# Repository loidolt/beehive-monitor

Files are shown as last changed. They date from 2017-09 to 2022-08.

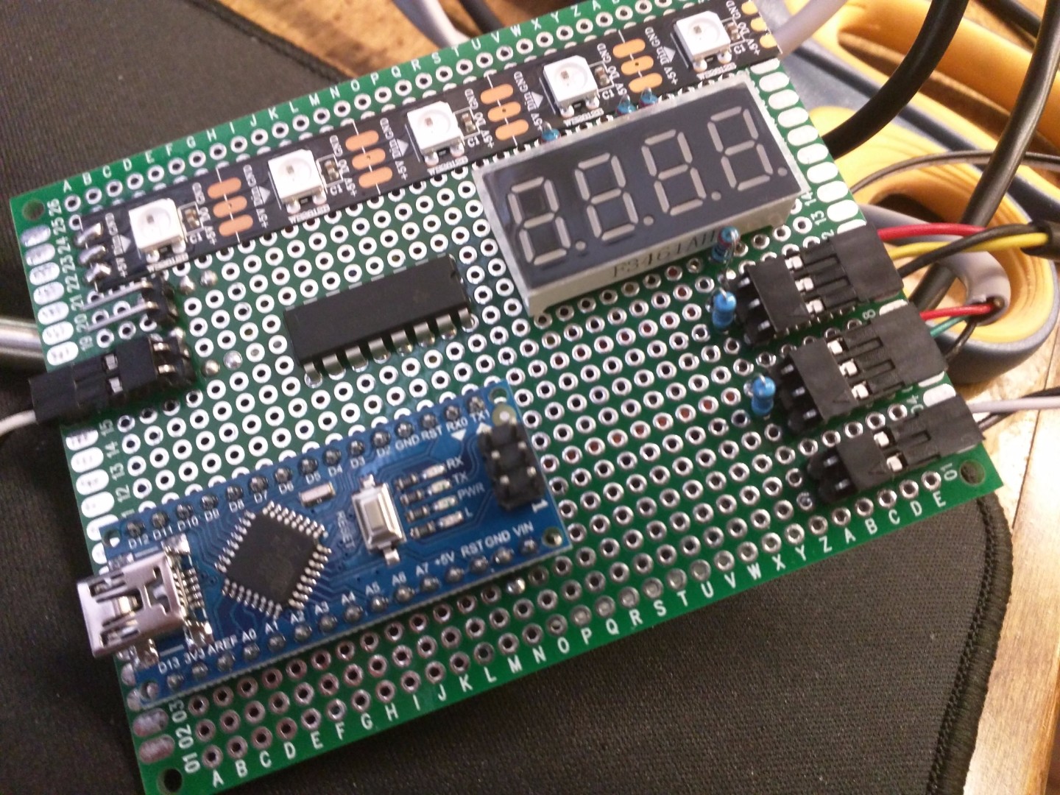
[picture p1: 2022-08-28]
images/BeeMonitorResized_Cover.jpg

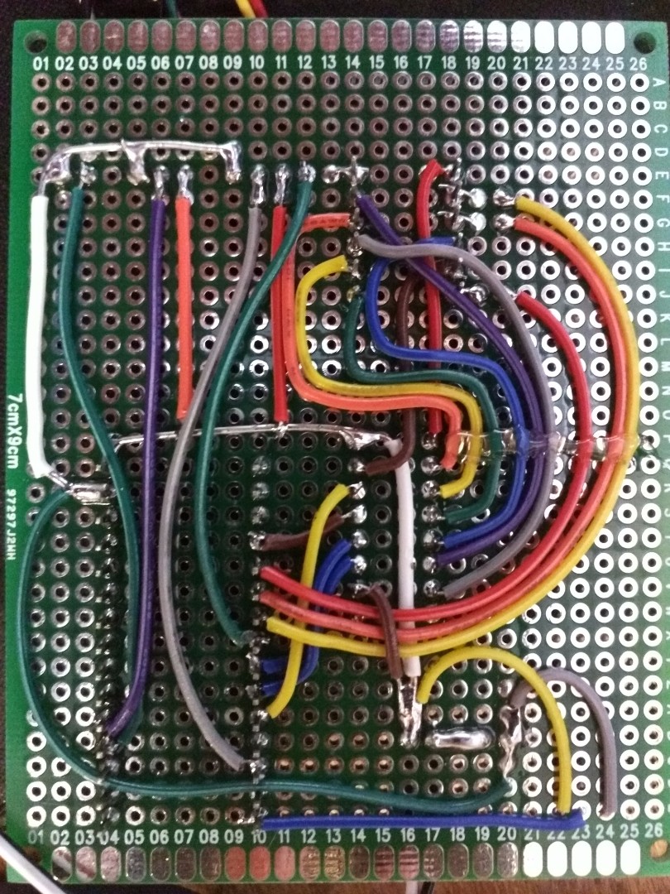
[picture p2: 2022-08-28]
images/BeeMonitorResized (1).jpg

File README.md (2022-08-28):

---
published: true
status: complete
date: 12/20/2016
tags: Electronics Outdoors
description: Beehive monitor that allows you to see the temperature and humidity of the hive.
slug: beehive-monitor
---

# Beehive Monitor

Beehive monitor that allows you to see the temperature and humidity of the hive.

## Table of Contents

- [Beehive Monitor](#beehive-monitor)
  - [Table of Contents](#table-of-contents)
  - [General Info](#general-info)
  - [Technologies](#technologies)

## General Info

This is is a beehive monitor that allows you to see the temperature and humidity of the hive. It also shows the general health of the hive using an LED strip based on ideal temperature and humidity values.

There are two temperature probes, one at the top of the hive and one that can be placed down by the hive ball to get a more accurate reading of the bees themselves. The temperature sensor at the top of the hive is also responsible for measuring humidity.

Sensor data is gathered once a minute, additionally, a rolling thirty-minute average is generated based on this data.

## Technologies
- SketchUp
- Eagle
- KiCAD
- Arduino

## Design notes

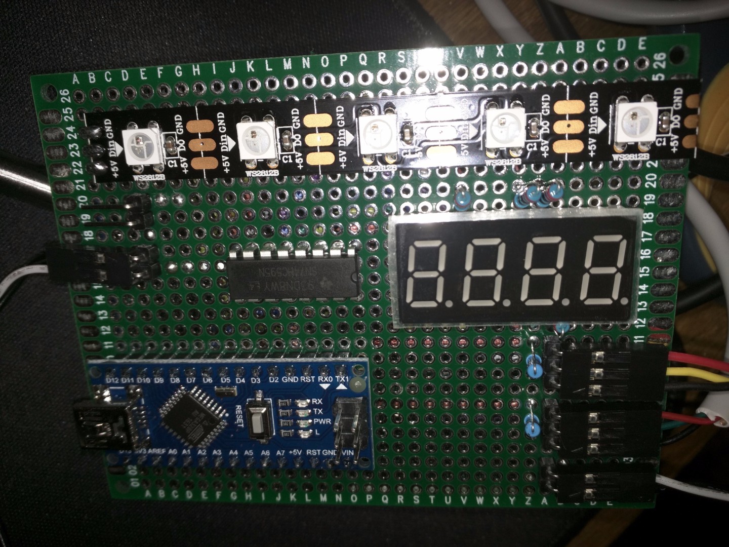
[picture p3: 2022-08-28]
images/BeeMonitorResized (7).jpg

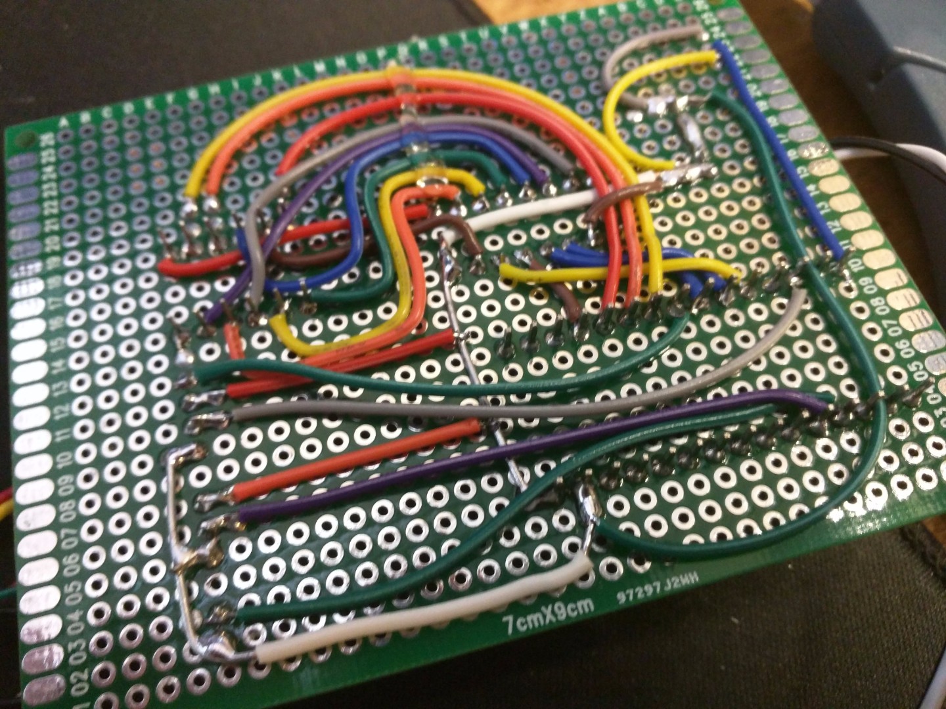
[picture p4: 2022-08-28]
images/BeeMonitorResized (3).jpg

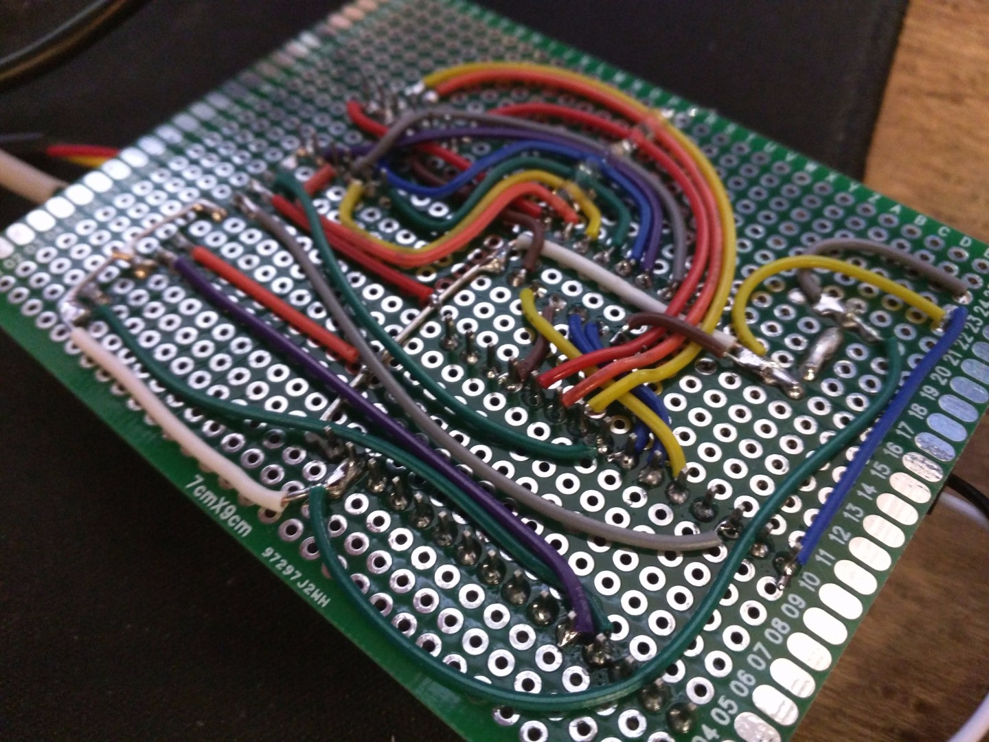
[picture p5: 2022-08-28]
images/BeeMonitorResized (4).jpg

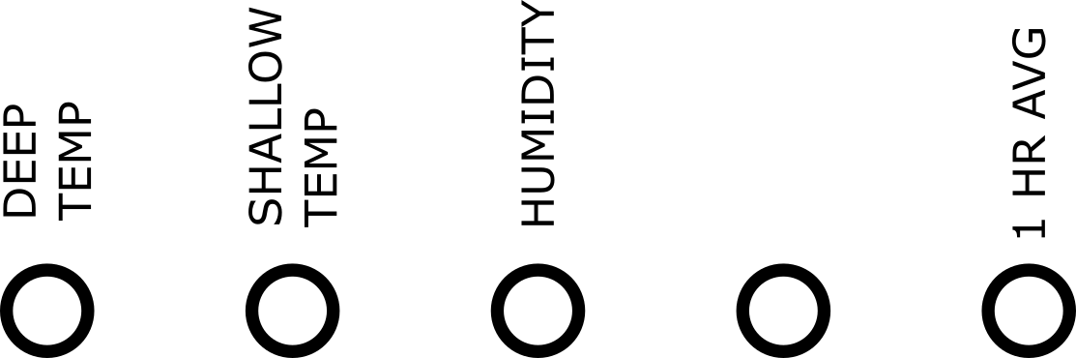
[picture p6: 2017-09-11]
firmware/SevenSegment/KeyGraphic.png

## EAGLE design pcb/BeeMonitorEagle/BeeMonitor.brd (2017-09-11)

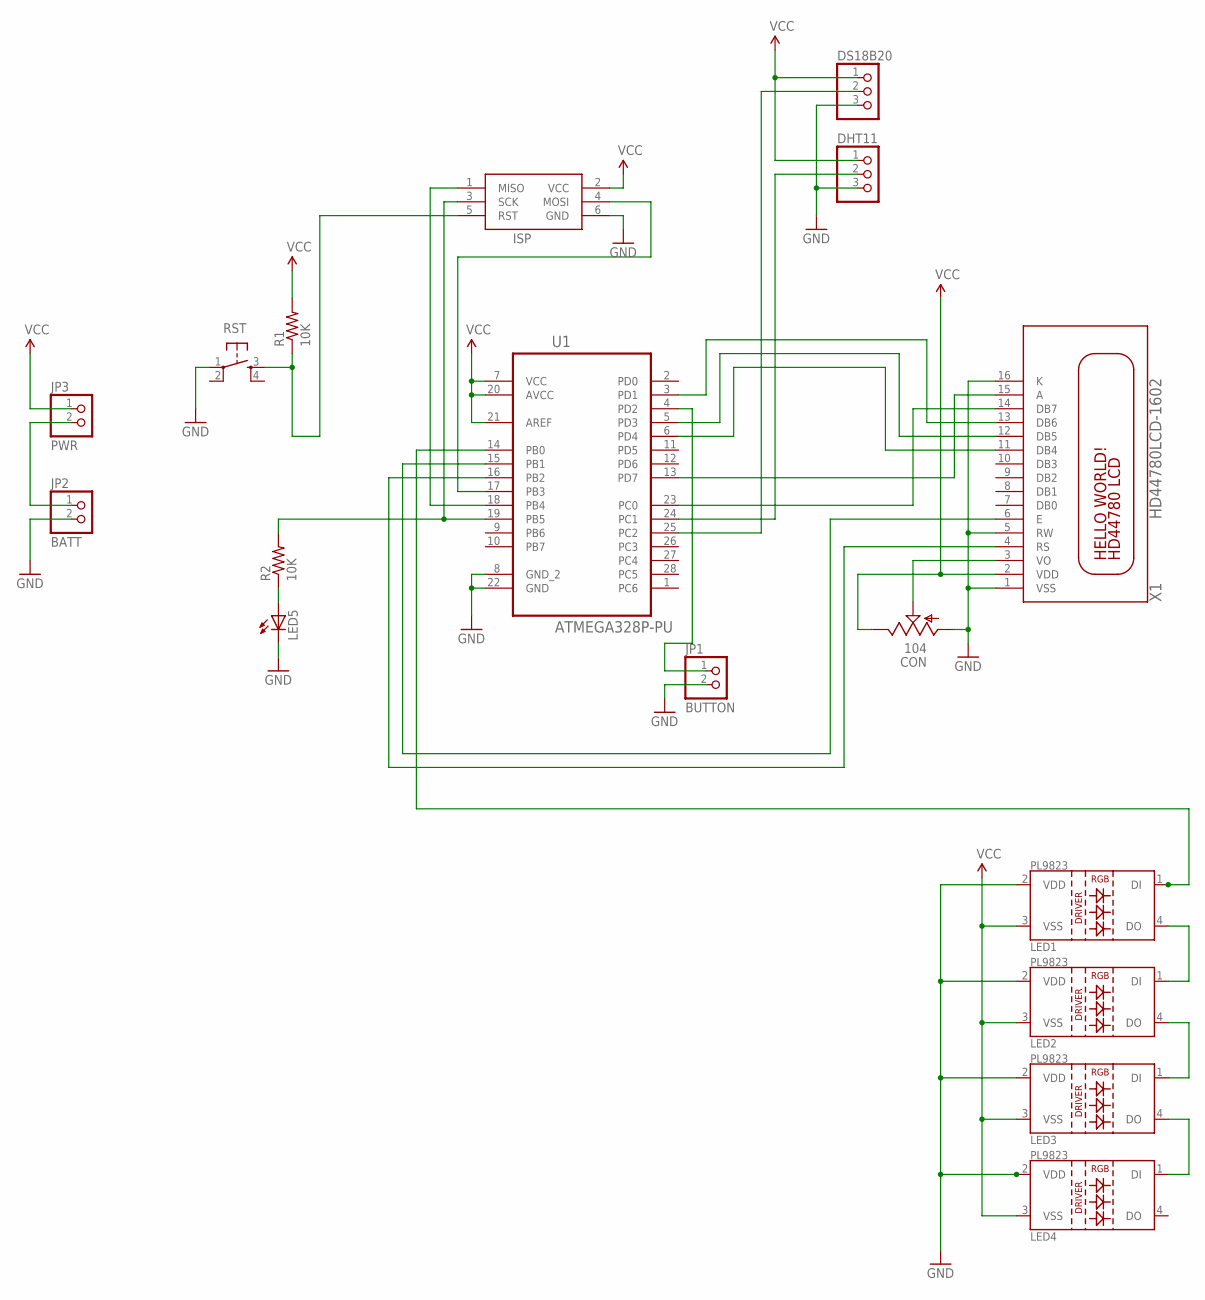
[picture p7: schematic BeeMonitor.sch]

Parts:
CON: 104; 6MM
DHT11: PINHD-1X3; 1X03
DS18B20: PINHD-1X3; 1X03
ISP: AVRISP-6; AVRISP
JP1: BUTTON; 1X02
JP2: BATT; 1X02
JP3: PWR; 1X02
LED1, LED2, LED3, LED4: LED-PL9823-F5
LED5: LED3MM
R1, R2: 10K; 0207/10
RST: TAC_SWITCHPTH; TACTILE-PTH
U1: ATMEGA328P-PU; DIP254P762X457-28
X1: HD44780LCD-1602; LCD1602

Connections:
GND: DHT11.3, DS18B20.3, ISP.6 (GND), JP1.2, JP2.2, LED1.2 (VDD), LED2.2 (VDD), LED3.2 (VDD), LED4.2 (VDD), LED5.K (C), RST.1, U1.8 (GND_2), U1.22 (GND)
unnamed: CON.S, X1.3 (VO)
unnamed: ISP.5 (RST), R1.1, RST.3
unnamed: ISP.3 (SCK), R2.2, U1.19 (PB5)
unnamed: ISP.1 (MISO), U1.18 (PB4)
unnamed: ISP.4 (MOSI), U1.17 (PB3)
unnamed: LED1.4 (DO), LED2.1 (DI)
unnamed: LED2.4 (DO), LED3.1 (DI)
unnamed: LED3.4 (DO), LED4.1 (DI)
unnamed: LED1.1 (DI), U1.14 (PB0)
unnamed: U1.3 (PD1), X1.13 (DB6)
unnamed: DHT11.2, U1.24 (PC1)
unnamed: DS18B20.2, U1.25 (PC2)
unnamed: JP1.1, U1.4 (PD2)
unnamed: U1.13 (PD7), X1.15 (A)
unnamed: U1.23 (PC0), X1.14 (DB7)
unnamed: U1.5 (PD3), X1.12 (DB5)
unnamed: U1.6 (PD4), X1.11 (DB4)
unnamed: U1.15 (PB1), X1.6 (E)
unnamed: U1.16 (PB2), X1.4 (RS)
unnamed: LED5.A, R2.1
unnamed: JP2.1, JP3.2
VCC: DHT11.1, DS18B20.1, ISP.2 (VCC), JP3.1, LED1.3 (VSS), LED2.3 (VSS), LED3.3 (VSS), LED4.3 (VSS), R1.2, U1.7 (VCC), U1.20 (AVCC), U1.21 (AREF)
VDD: CON.E, X1.2 (VDD)
VSS: CON.A, X1.1 (VSS), X1.5 (RW), X1.16 (K)

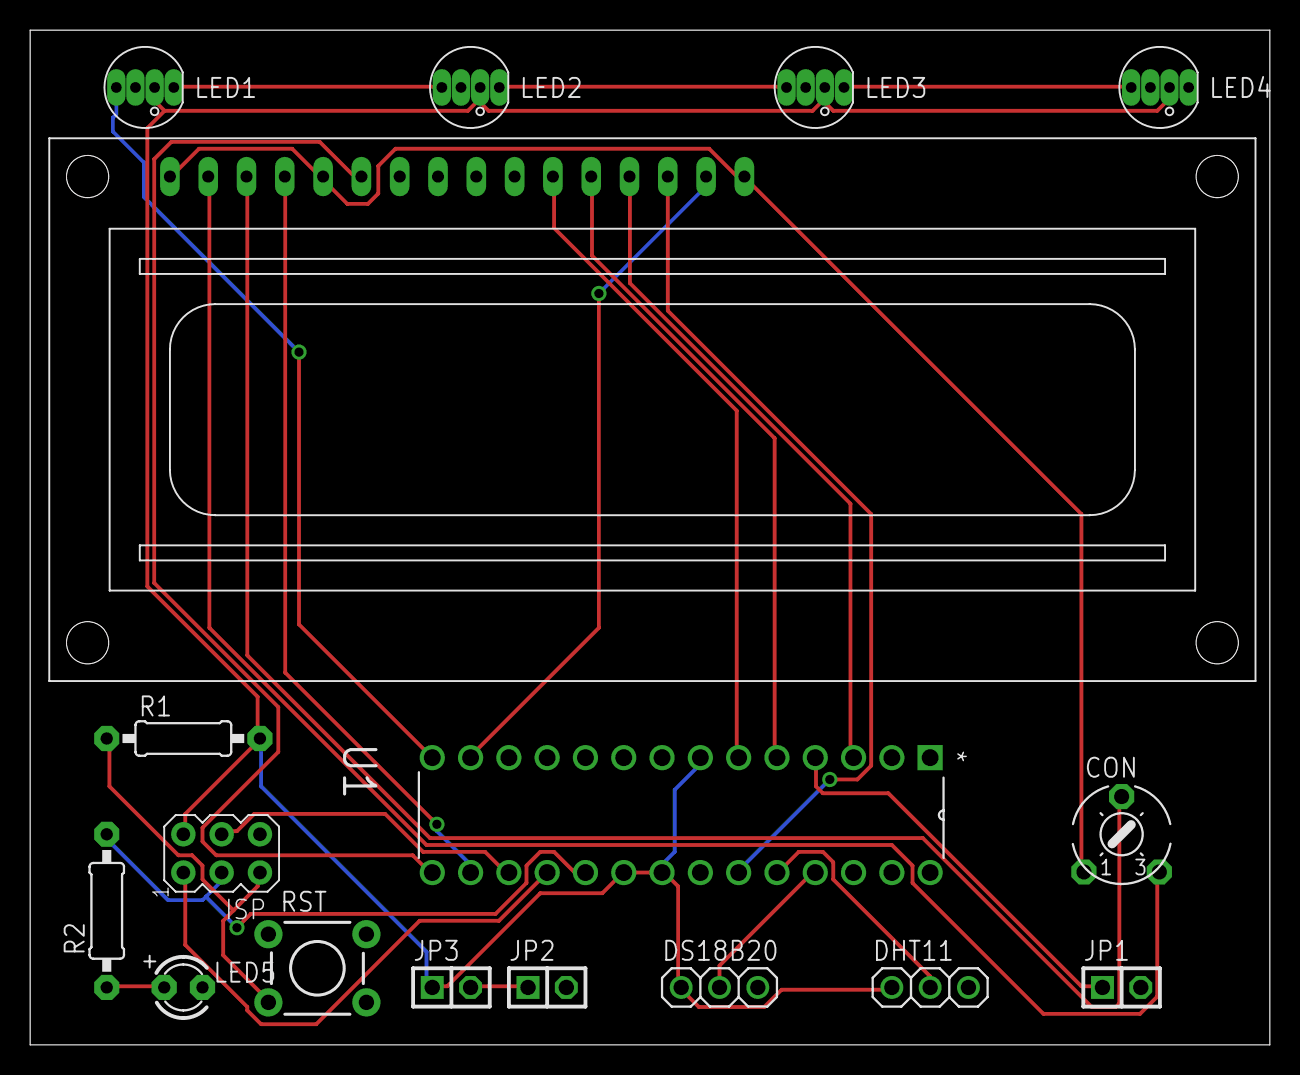
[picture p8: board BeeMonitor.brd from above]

Board: 2 copper layers, 82.2 x 67.3 mm, 17 parts (0 on the bottom side), 25 nets.

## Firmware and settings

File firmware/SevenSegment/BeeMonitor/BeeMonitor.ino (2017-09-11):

/*
* BeeMonitor V1
* Chris Loidolt
* 
* References:
* Temperature Sensor Displayed on 4 Digit 7 segment common CATHODE
* https://gist.github.com/ruisantos16/5419223
* 
* Averaging Library
* https://github.com/MajenkoLibraries/Average
* 
*/
#include "FastLED.h"
#include "Button.h"                                           // Button library. Includes press, long press, double press detection.
#include <DHT.h>
#include <DHT_U.h>
#include <DallasTemperature.h>
#include <OneWire.h>
#include <Average.h>

// FastLED Setup
#if FASTLED_VERSION < 3001000
#error "Requires FastLED 3.1 or later; check github for latest code."
#endif

#define DATA_PIN   12
#define LED_TYPE    WS2812
#define COLOR_ORDER GRB
#define NUM_LEDS    5
#define BRIGHTNESS  10
CRGB leds[NUM_LEDS];

#define FRAMES_PER_SECOND  30

// DHT11 setup
#define DHTTYPE DHT11   // DHT 11
#define DHTPIN A1
DHT dht(DHTPIN, DHTTYPE);

// DS18B20 setup
#define ONE_WIRE_BUS 10
OneWire ds(ONE_WIRE_BUS);
DallasTemperature sensors(&ds);

// Pushbutton pin definition
const int BUTTON_PIN = A0;                                      // Digital pin used for debounced pushbutton

bool oldState = HIGH;
int showType = 0;

// Display setup
const int digitPins[4] = {5,4,3,2}; //4 common CATHODE pins of the display (inverted the pins order)
const int clockPin = 6;    //74HC595
const int latchPin = 7;    //74HC595
const int dataPin = 8;     //74HC595
const byte digit[10] =      //seven segment digits in bits
{
  B00111111, //0
  B00000110, //1
  B01011011, //2
  B01001111, //3
  B01100110, //4
  B01101101, //5
  B01111101, //6
  B00000111, //7
  B01111111, //8
  B01101111  //9
};
int digitBuffer[4] = {0};
int digitScan = 0;

// Status Variables
float tempS;
float tempD;
float humid;
float avgTempS;
float avgTempD;
float avgHumid;

// Average Readings
Average <int>tempDArray(60);
Average <int>tempSArray(60);
Average <int>humidArray(60);

// Reference Values
float idealTemp = 95;
float warningTempLow = 55;
float dangerTempLow = 46;

float idealHumid = 55;
float warningHumidLow = 45;
float warningHumidHigh = 75;
float dangerHumidLow = 35;
float dangerHumidHigh = 85;

void setup(){
  delay(1000);
  
  pinMode(BUTTON_PIN, INPUT_PULLUP);

  FastLED.addLeds<LED_TYPE,DATA_PIN,COLOR_ORDER>(leds, NUM_LEDS).setCorrection(TypicalLEDStrip);
  FastLED.setBrightness( BRIGHTNESS );
  
  for(int i=0;i<4;i++)
  {
    pinMode(digitPins[i],OUTPUT);
  }
  pinMode(latchPin, OUTPUT);
  pinMode(clockPin, OUTPUT);
  pinMode(dataPin, OUTPUT); 
  
  //Serial.begin(9600);
  //Serial.println("Bee Monitor");

  dht.begin();
  sensors.begin();
  startup();
}

// List of modes to cycle through.  Each is defined as a separate function below.
typedef void (*SimplePatternList[])();
SimplePatternList gPatterns = {idle, tempDeep, tempShallow, humidity, tempDeepAvg, tempShallowAvg, humidityAvg };

uint8_t gCurrentPatternNumber = 0; // Index number of which pattern is current

void loop(){
  // Check sensors every minute
  const unsigned long minutes = 1 * 60 * 1000UL;
  static unsigned long lastSampleTime = 0 - minutes;  // initialize such that a reading is due the first time through loop()
  
  unsigned long now = millis();
  if (now - lastSampleTime >= minutes)
  {
    lastSampleTime += minutes;
    updateSensors();
  }
  
  // Call the current mode once, updating the display
  gPatterns[gCurrentPatternNumber]();
  
  FastLED.show();
  
  readbutton();
}

#define ARRAY_SIZE(A) (sizeof(A) / sizeof((A)[0]))

void nextPattern()
{
  // add one to the current pattern number, and wrap around at the end
  gCurrentPatternNumber = (gCurrentPatternNumber + 1) % ARRAY_SIZE( gPatterns);
}

void idle(){
  
  fill_solid(leds, NUM_LEDS, CRGB::Black);
  
  if (tempD <= dangerTempLow || humid <= dangerHumidLow || humid >= dangerHumidHigh){
    for( int i = 0; i < 4; i++) {
        leds[i] = CRGB::Red;
    }
  }
  else if (tempD <= warningTempLow || humid <= warningHumidLow || humid >= warningHumidHigh){
    for( int i = 0; i < 4; i++) {
        leds[i] = CRGB::Yellow;
    }
  }
  else {
    for( int i = 0; i < 4; i++) {
        leds[i] = CRGB::Green;
    }
  }
  
  if (avgTempD <= dangerTempLow || avgHumid <= dangerHumidLow || avgHumid >= dangerHumidHigh){
    leds[4] = CRGB::Red;
  }
  else if (avgTempS <= warningTempLow || avgHumid <= warningHumidLow || avgHumid >= warningHumidHigh){
    leds[4] = CRGB::Yellow;
  }
  else {
    leds[4] = CRGB::Green;
  }
  
  for(byte j=0; j<4; j++) {digitalWrite(digitPins[j], HIGH);} // Turns the display off
  
}

void tempDeep(){
  //Serial.print("Deep Temperature: ");
  //Serial.println(tempD);

  fill_solid(leds, NUM_LEDS, CRGB::Black);
  leds[0] = CRGB::Yellow;

  int D = tempD * 100;

  digitBuffer[3] = D/1000;
  digitBuffer[2] = (D%1000)/100;
  digitBuffer[1] = (D%100)/10;
  digitBuffer[0] = (D%100)%10;
  updateDisp();
}

void tempShallow(){
  //Serial.print("Shallow Temperature: ");
  //Serial.println(tempS);

  fill_solid(leds, NUM_LEDS, CRGB::Black);
  leds[1] = CRGB::Yellow;

  int S = tempS * 100;
  
  digitBuffer[3] = S/1000;
  digitBuffer[2] = (S%1000)/100;
  digitBuffer[1] = (S%100)/10;
  digitBuffer[0] = (S%100)%10;
  updateDisp();
}

void humidity(){
  //Serial.print("Humidity: ");
  //Serial.println(humid);

  fill_solid(leds, NUM_LEDS, CRGB::Black);
  leds[2] = CRGB::Yellow;

  int H = humid * 100;

  digitBuffer[3] = H/1000;
  digitBuffer[2] = (H%1000)/100;
  digitBuffer[1] = (H%100)/10;
  digitBuffer[0] = (H%100)%10;
  updateDisp();
}

void tempDeepAvg(){
  //Serial.print("Average Deep Temperature: ");
  //Serial.println(avgTempD);

  fill_solid(leds, NUM_LEDS, CRGB::Black);
  leds[0] = CRGB::Yellow;
  leds[4] = CRGB::Yellow;

  int DA = avgTempD * 100;

  digitBuffer[3] = DA/1000;
  digitBuffer[2] = (DA%1000)/100;
  digitBuffer[1] = (DA%100)/10;
  digitBuffer[0] = (DA%100)%10;
  updateDisp();
}

void tempShallowAvg(){
  //Serial.print("Average Shallow Temperature: ");
  //Serial.println(avgTempS);

  fill_solid(leds, NUM_LEDS, CRGB::Black);
  leds[1] = CRGB::Yellow;
  leds[4] = CRGB::Yellow;

  int DS = avgTempS * 100;

  digitBuffer[3] = DS/1000;
  digitBuffer[2] = (DS%1000)/100;
  digitBuffer[1] = (DS%100)/10;
  digitBuffer[0] = (DS%100)%10;
  updateDisp();
}

void humidityAvg(){
  //Serial.print("Average Humidity: ");
  //Serial.println(avgHumid);

  fill_solid(leds, NUM_LEDS, CRGB::Black);
  leds[2] = CRGB::Yellow;
  leds[4] = CRGB::Yellow;

  int HA = avgHumid * 100;

  digitBuffer[3] = HA/1000;
  digitBuffer[2] = (HA%1000)/100;
  digitBuffer[1] = (HA%100)/10;
  digitBuffer[0] = (HA%100)%10;
  updateDisp();
}

void updateDisp(){ //writes the display
  
  for(byte j=0; j<4; j++) {digitalWrite(digitPins[j], HIGH);} // Turns the display off. Changed to HIGH
  digitalWrite(latchPin, LOW); 
  shiftOut(dataPin, clockPin, MSBFIRST, B00000000);
  digitalWrite(latchPin, HIGH);

  delayMicroseconds(2);

  digitalWrite(digitPins[digitScan], LOW); //Changed to LOW for turning the leds on.

  digitalWrite(latchPin, LOW); 
  if(digitScan==2)
    shiftOut(dataPin, clockPin, MSBFIRST, (digit[digitBuffer[digitScan]] | B10000000)); //print the decimal point on the 3rd digit
  else
    shiftOut(dataPin, clockPin, MSBFIRST, digit[digitBuffer[digitScan]]);

  digitalWrite(latchPin, HIGH);

  digitScan++;
  if(digitScan>3) digitScan=0;
}

void updateSensors(){                                           // Check the sensors and update values
  
  tempS = dht.readTemperature(true);
  humid = dht.readHumidity();

  sensors.requestTemperatures();
  tempD = sensors.getTempFByIndex(0);

  // Push values into averaging arrays
  tempDArray.push(tempD);
  tempSArray.push(tempS);
  humidArray.push(humid);

  // Calculate averages from stored arrays
  avgTempD = tempDArray.mean();
  avgTempS = tempSArray.mean();
  avgHumid = humidArray.mean();
    
}

void readbutton(){                                           // Read the button and increase the mode
  // Get current button state.
  bool newState = digitalRead(BUTTON_PIN);

  // Check if state changed from high to low (button press).
  if (newState == LOW && oldState == HIGH) {
    // Short delay to debounce button.
    delay(100);
    // Check if button is still low after debounce.
    newState = digitalRead(BUTTON_PIN);
    if (newState == LOW) {
      nextPattern();
  }
}
}

void startup(){
  
  for(byte j=0; j<4; j++) {digitalWrite(digitPins[j], HIGH);} // Turns the display off
  
  fill_solid(leds, NUM_LEDS, CRGB::Black);
  
  for( int i = 0; i < NUM_LEDS; i++) {
        leds[i] = CRGB::Yellow;
        delay(300);
        FastLED.show();
    }
}

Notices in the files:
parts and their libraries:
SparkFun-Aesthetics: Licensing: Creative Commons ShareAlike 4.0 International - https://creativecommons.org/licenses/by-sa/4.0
